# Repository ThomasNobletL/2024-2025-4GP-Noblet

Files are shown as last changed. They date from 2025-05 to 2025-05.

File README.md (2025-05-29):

<h1 align = "center"> Projet Capteur Graphite 4A - GP <h1> 
<h2 align="center"> Par NOBLET Thomas </h2>
<h3 align="center"> INSA de Toulouse, département Génie Physique, année 2024 - 2025 </h3>
  
<p align="center">
  <a href="http://www.gnu.org/licenses/gpl-3.0">
    
  </a>
</p>

## <h2 align = "center"> Mesure de contrainte sous arduino & python d'un capteur graphite <h1>

### 1. Description

*Contexte*

Le projet consiste à reproduire une technologie low-tech de capteur de flexion en graphite, se basant sur l'article "Pencil Drawn Strain Gauges and Chemiresistors on Paper" de Cheng-Wei Lin, Zhibo Zhao, Jaemyung Kim & Jiaxing Huang.

*Principe*

Des traces de crayons sur du papier se comportent comme des résistances dont la valeur varie en fonction de la courbure du papier sur lequel elles sont dessinées. 

*Contenu du projet*

Une [datasheet du capteur](05_DataSheet/Graphite_Sensor_DATA_SHEET.pdf) a pu être réalisée à l'aide d'une carte Arduino Uno, d'un circuit d'amplification (dont le PCB a été réalisé sur KICAD) et d'une interface python.

***Matériel utilisé (non exhaustif)***
- **Capteur de contrainte en graphite** : Mine HB conseillée
- **LTC1050** : Amplificateur du circuit 
- **MCP 41050** : Permet de faire varier le gain du circuit d'amplification
- **Module Bluetooth HC-05** : Récupérer les données en Bluetooth  
- **Ecran OLED SS1306 en I2C** : Affichage des données sur le PCB

### 2. Circuit d'amplification & PCB

Le circuit d'amplification utilise un amplificateur LTC1050 avec un gain de R2/R1. La résistance R1 est un potentiomètre MCP41050 (de 125Ω à 50kΩ) donnant une plage de gain de 2 à 800.

<p align="center">

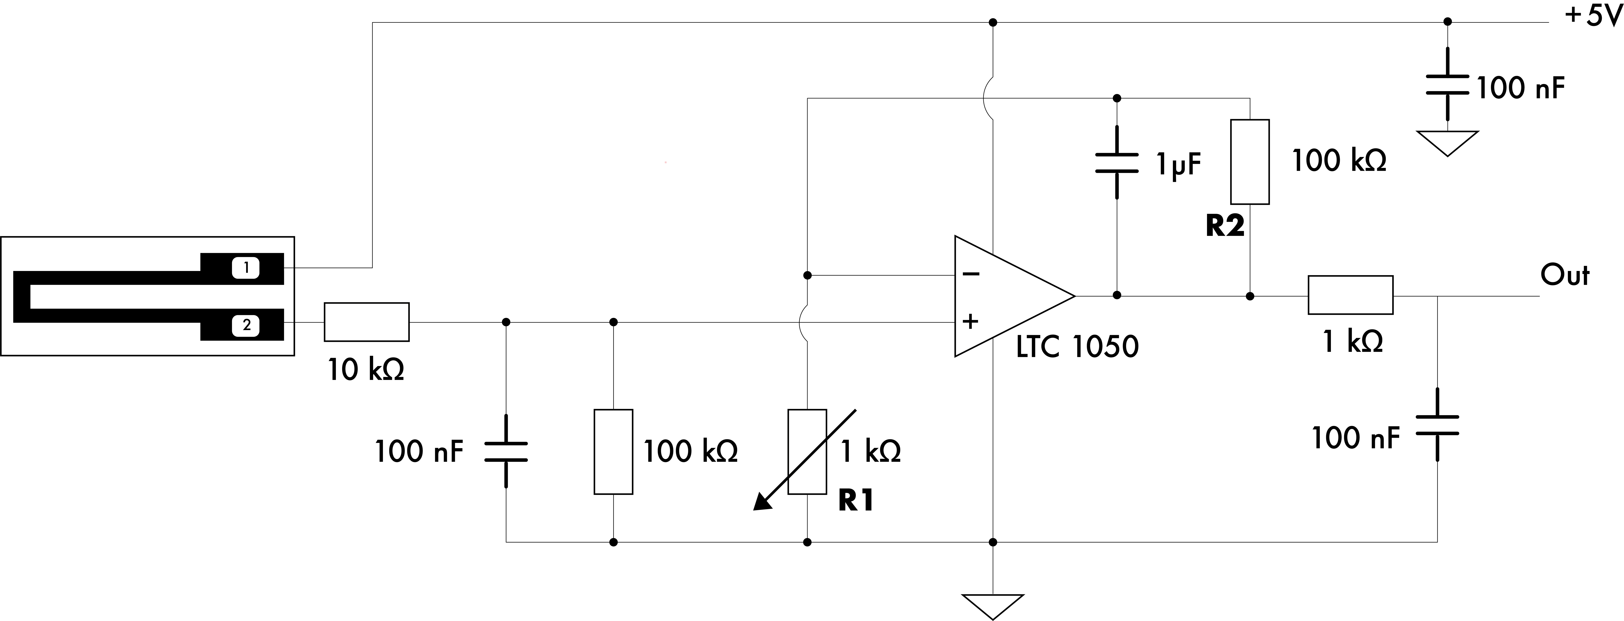
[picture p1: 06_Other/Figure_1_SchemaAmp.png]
Schéma Amplification
  
</p>

<p align="center"><em>Figure 1 : Schéma Amplification </em></p>

<p align="center">

  Circuit réel
</p>
<p align="center"><em>Figure 2 : Circuit réel </em></p>

Le PCB utilisé est celui-ci, avec les pins Rx et Tx de l'arduino connectées au HC05 (PCB Incorrect). Cette configuration est utilisable si on souhaite uploader le code arduino directement en bluetooth, mais il faut impérativement utiliser les pins 2 et 3 pour un upload depuis le port USB. Les pins 0 et 1 sont également utilisées par la liaison série vers un PC, ce qui provoque des erreurs en utilisant la connexion bluetooth sur ce port.

<p align="center">

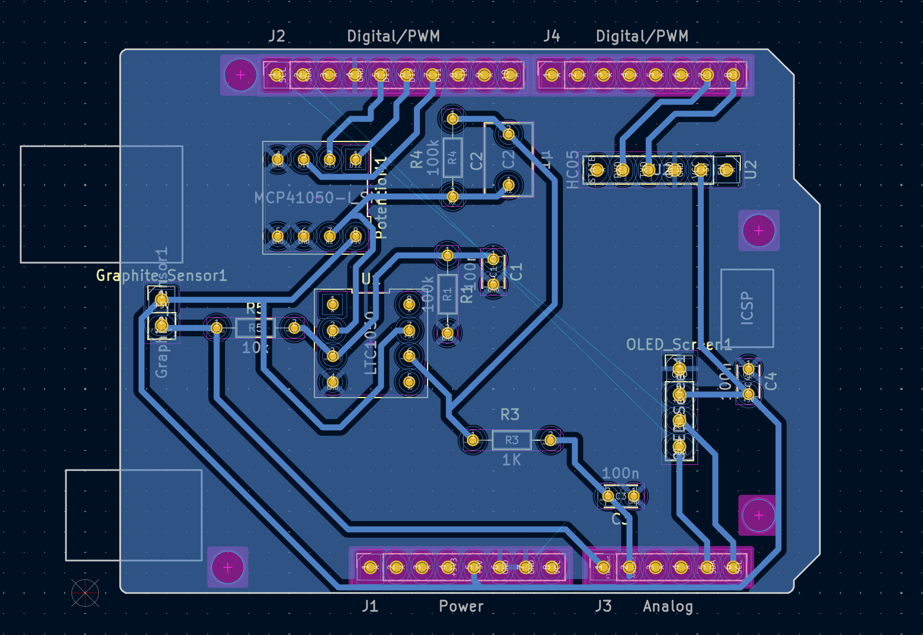
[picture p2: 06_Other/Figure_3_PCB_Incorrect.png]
PCB Incorrect
  
</p>
<p align="center"><em>Figure 3 : PCB Incorrect </em></p>

En l'occurence, aucun des codes python et arduino fournis fonctionnera durablement avec le premier PCB (30s), une erreurs série arrivera relativement rapidement, le PCB a donc été modifié à l'aide de câble pour correspondre à ce nouveau PCB. 

<p align="center">

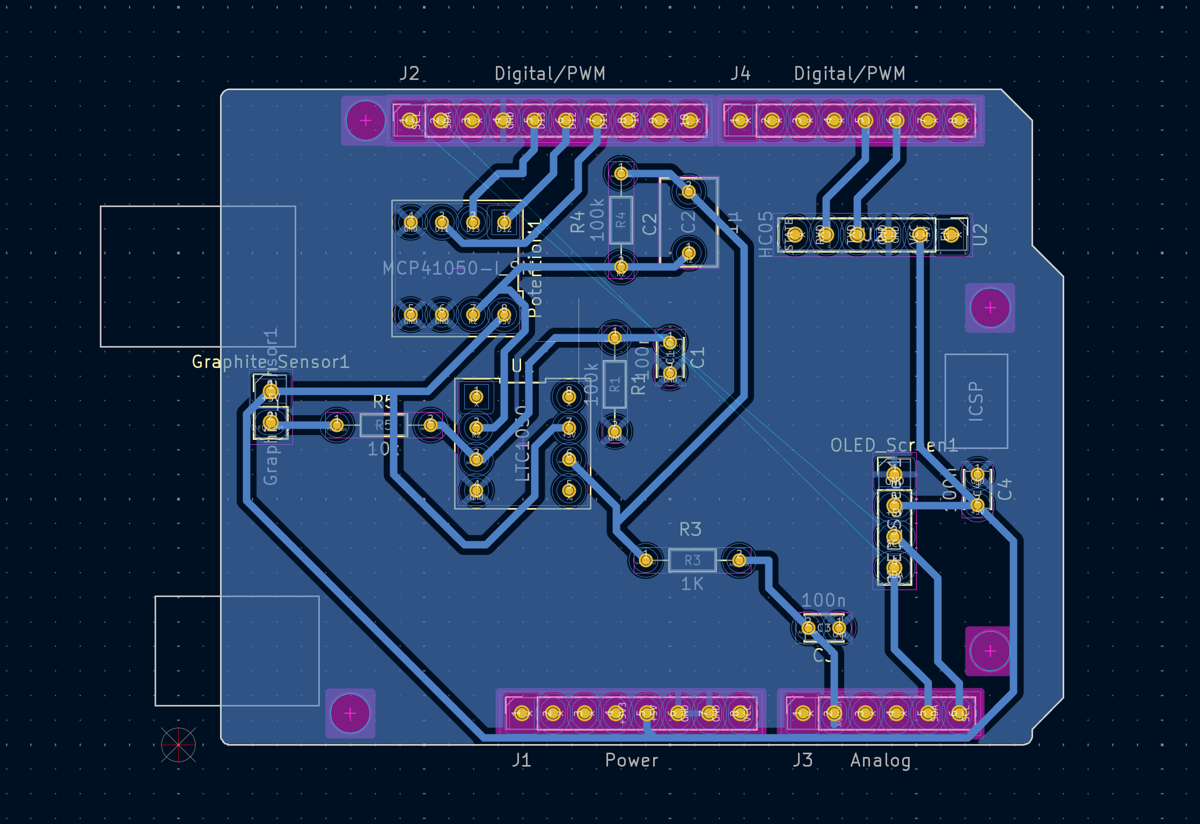
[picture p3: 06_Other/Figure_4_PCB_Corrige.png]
PCB Corrigé
  
</p>
<p align="center"><em>Figure 4 : PCB Corrigé</em></p>

### 3. Interface & code Python 

L'architecture du code est décrite si dessous. La valeur de la résistance ainsi que l'affichage des mesures se fait directement depuis l'interface Qt, qui communique avec un thread gérant l'acquisition et l'envoie de données vers l'arduino qui les réceptionnes. Le code fonctionne à la fois en liaison série et bluetooth, il suffit de choisir depuis "Port choice".

Une valeur du gain observé est affichée dans l'interface, mais ne permet que d'obtenir un ordre de grandeur, la sensibilité des mesures sur l'arduino étant de 4,88 mV et le signal d'entrée trop faible (d'où l'intérêt du circuit d'amplification).

<p align="center">

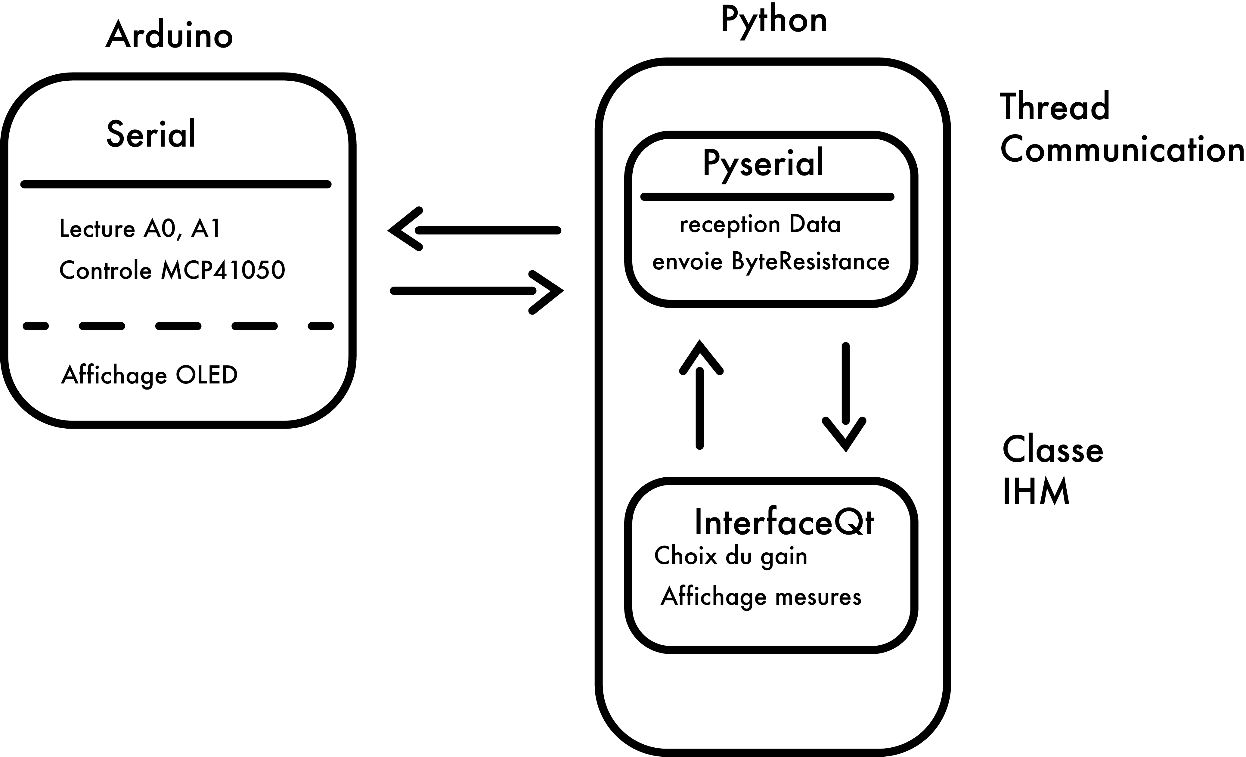
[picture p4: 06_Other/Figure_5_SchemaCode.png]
Architecture du code
  
</p>

<p align="center"><em>Figure 5 : Architecture du code</em></p>

<p align="center">

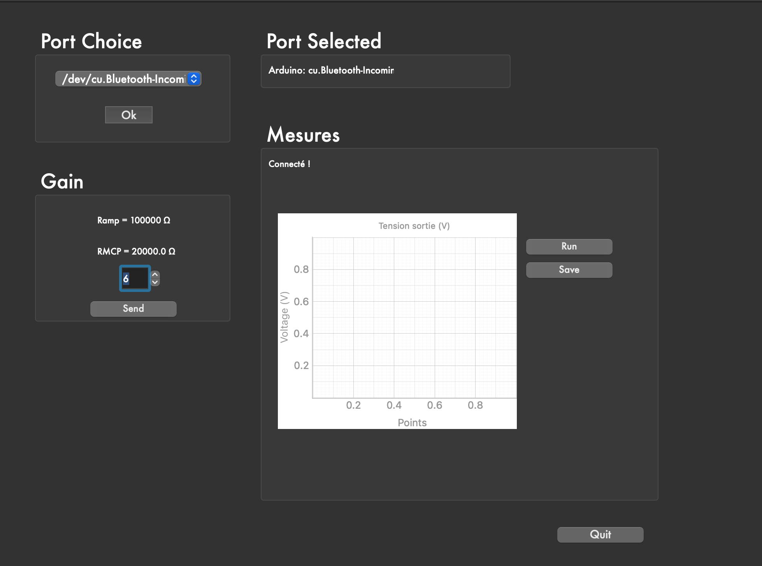
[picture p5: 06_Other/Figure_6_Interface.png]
  
</p>

<p align="center"><em>Figure 5 : Interface Qt</em></p>

Le "run" permet de lancer le stockage des données reçues, mais écrase la précédente série réalisée, il faut donc sauvegarder directement après la fin de l'acquisition si le but est de prendre plusieurs séries d'affilée. 

### 4. Résultats

Les mesures ont été effectuées à l'aide de cylindres de diamètre **D** de **2, 2.5, 3, 3.5, 4, 4.5 et 5 cm** ainsi que de crayons de mines HB, 2B et 4B.
Avec la déformation $\epsilon$ = e/D, e étant l'épaisseur du papier (0,1 mm).

<p align="center">

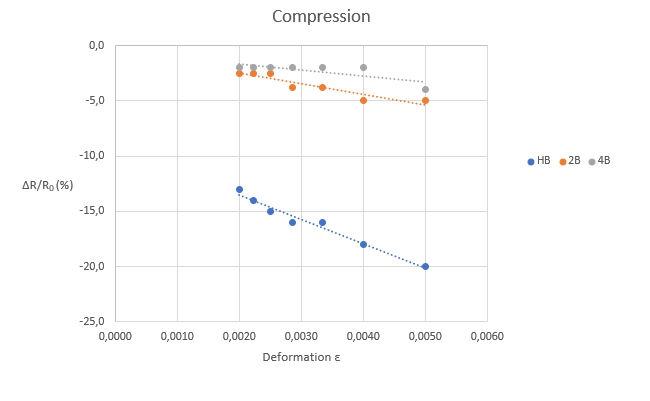
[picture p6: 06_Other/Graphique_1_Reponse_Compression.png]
Réponse en compression
  
</p>

<p align="center"><em>Graphique 1 : Réponse en compression</em></p>

<p align="center">

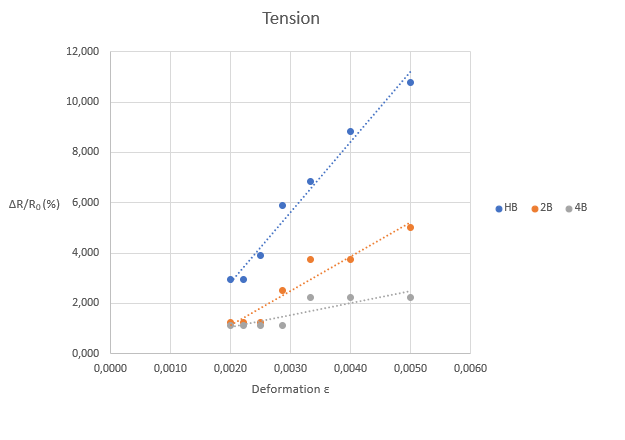
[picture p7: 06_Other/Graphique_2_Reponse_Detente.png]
Réponse en détente
  
</p>
<p align="center"><em>Graphique 2 : Réponse en détente</em></p>

On remarque que la variation de résistance en compression et en détente est plus importante pour une mine moyennement dure et grasse (HB) que pour des mines plus grasses (2B, 4B).

<p align="center">

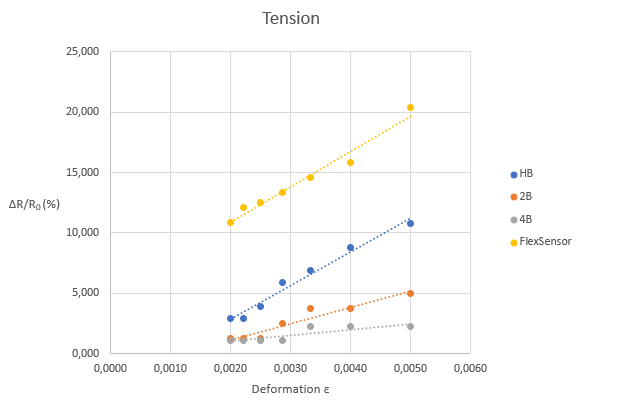
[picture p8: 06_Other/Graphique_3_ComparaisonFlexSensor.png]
Comparaison avec un Flex sensor
  
</p>

<p align="center"><em>Graphique 3 : Comparaison avec un Flex sensor  </em></p>

En comparant avec un flex sensor de Spectra Symbol, on remarque que la réponse en détente est assez cohérente avec celle du capteur en graphite produit (le flex sensor de Spectra Symbol ne permet pas de comparer en compression, [Datasheet](06_Other/FLEX_SENSOR_-_SPECIAL_EDITION_DATA_SHEET.pdf)). De plus, les mesures on étés prises sans utiliser le circuit d'amplification. 

### 5. Limites et perspectives

*Le Bluetooth du HC-05*

  La connexion entre le module HC-05 et un PC est **trop instable** pour utiliser seulement l'interface python fournie **sur Mac OS**, l'appairage échoue souvent ou se coupe régulièrement. Il est préférable d'utiliser une connexion avec un port série. 
  
*Utilisation d'un module Wifi ESP32*

  Remplacer le HC-O5 par un module Wifi ESP32 pourrait permettre de se connecter plus aisément avec les OS Mac sur un même réseau et également en bluetooth.

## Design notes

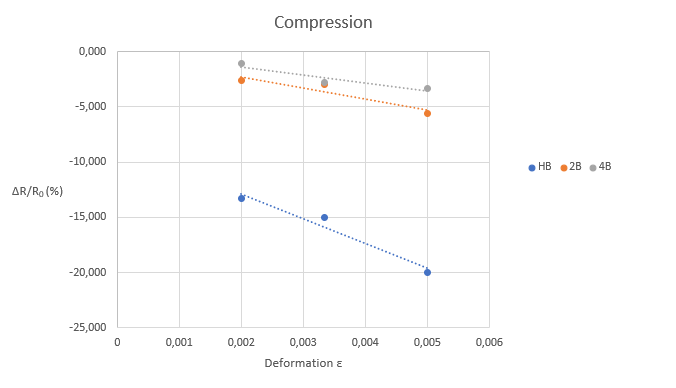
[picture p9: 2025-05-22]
06_Other/01_Preparations/Compression_from_Pc.png

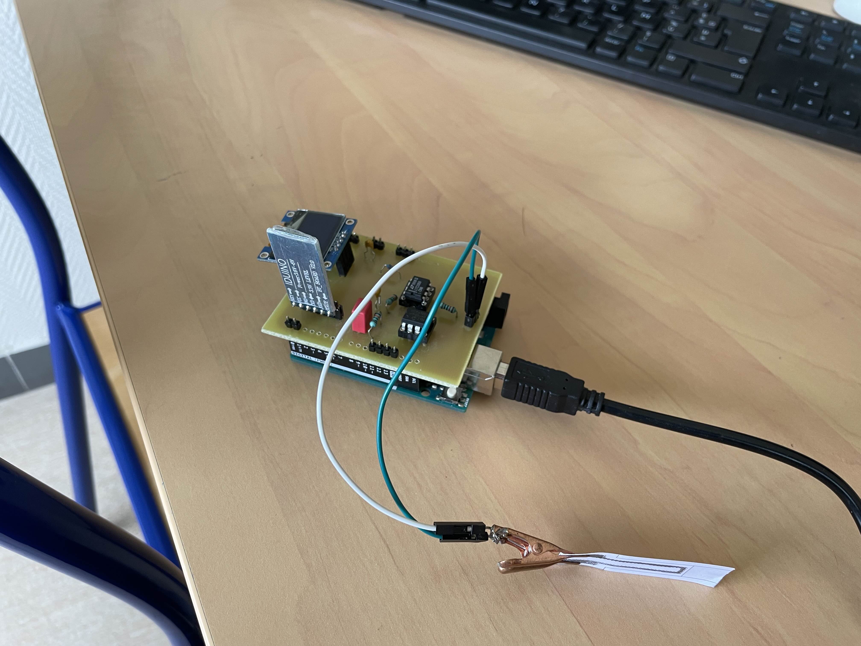
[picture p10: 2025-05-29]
06_Other/01_Preparations/Figure_2_Final.jpg

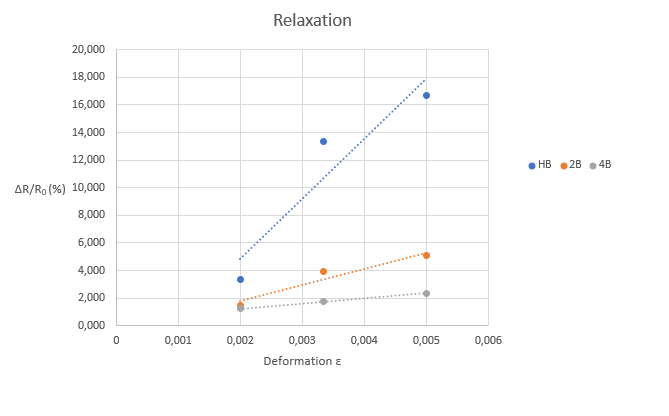
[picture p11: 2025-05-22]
06_Other/01_Preparations/Relaxation_from_Pc.png

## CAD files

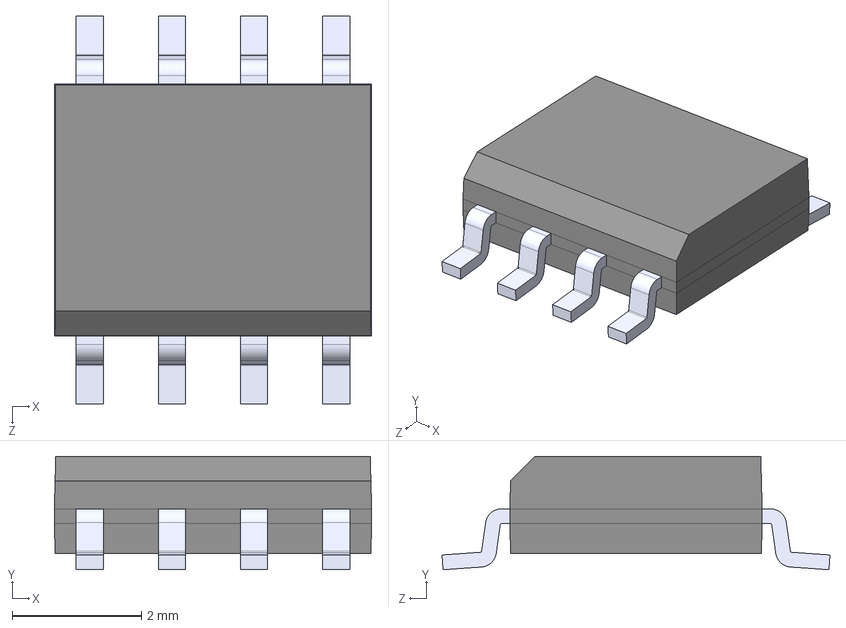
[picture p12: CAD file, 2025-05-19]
02_Kicad/04_Empreinte_from_Web/LTC1050HS8_TRPBF/LTC1050HS8_TRPBF.step
4.90 x 1.75 x 5.99 mm

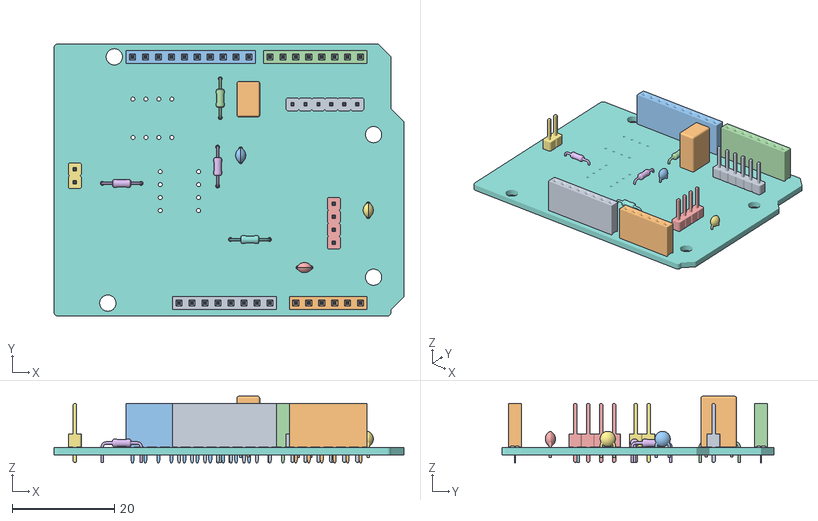
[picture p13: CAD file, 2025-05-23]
06_Other/01_Preparations/PCB-Blender.obj
68.6 x 53.3 x 13.1
PinSocket_1x08_P2.54mm_Vertical
PinSocket_1x06_P2.54mm_Vertical
PinSocket_1x10_P2.54mm_Vertical
PinSocket_1x08_P2.54mm_Vertical001
C_Disc_D3.0mm_W2.0mm_P2.50mm
R_Axial_DIN0204_L3.6mm_D1.6mm_P7.62mm_Horizontal
PinHeader_1x02_P2.54mm_Vertical
R_Axial_DIN0204_L3.6mm_D1.6mm_P7.62mm_Horizontal001
PinHeader_1x06_P2.54mm_Vertical
C_Rect_L7.0mm_W4.5mm_P5.00mm
C_Disc_D3.0mm_W2.0mm_P2.50mm001
R_Axial_DIN0204_L3.6mm_D1.6mm_P7.62mm_Horizontal002
PinHeader_1x04_P2.54mm_Vertical
R_Axial_DIN0204_L3.6mm_D1.6mm_P7.62mm_Horizontal003
C_Disc_D3.0mm_W2.0mm_P2.50mm002
Graphite_PCB

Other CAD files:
06_Other/Graphite.step
02_Kicad/04_Empreinte_from_Web/MCP41050-I_SN/MCP41050-I_SN.step

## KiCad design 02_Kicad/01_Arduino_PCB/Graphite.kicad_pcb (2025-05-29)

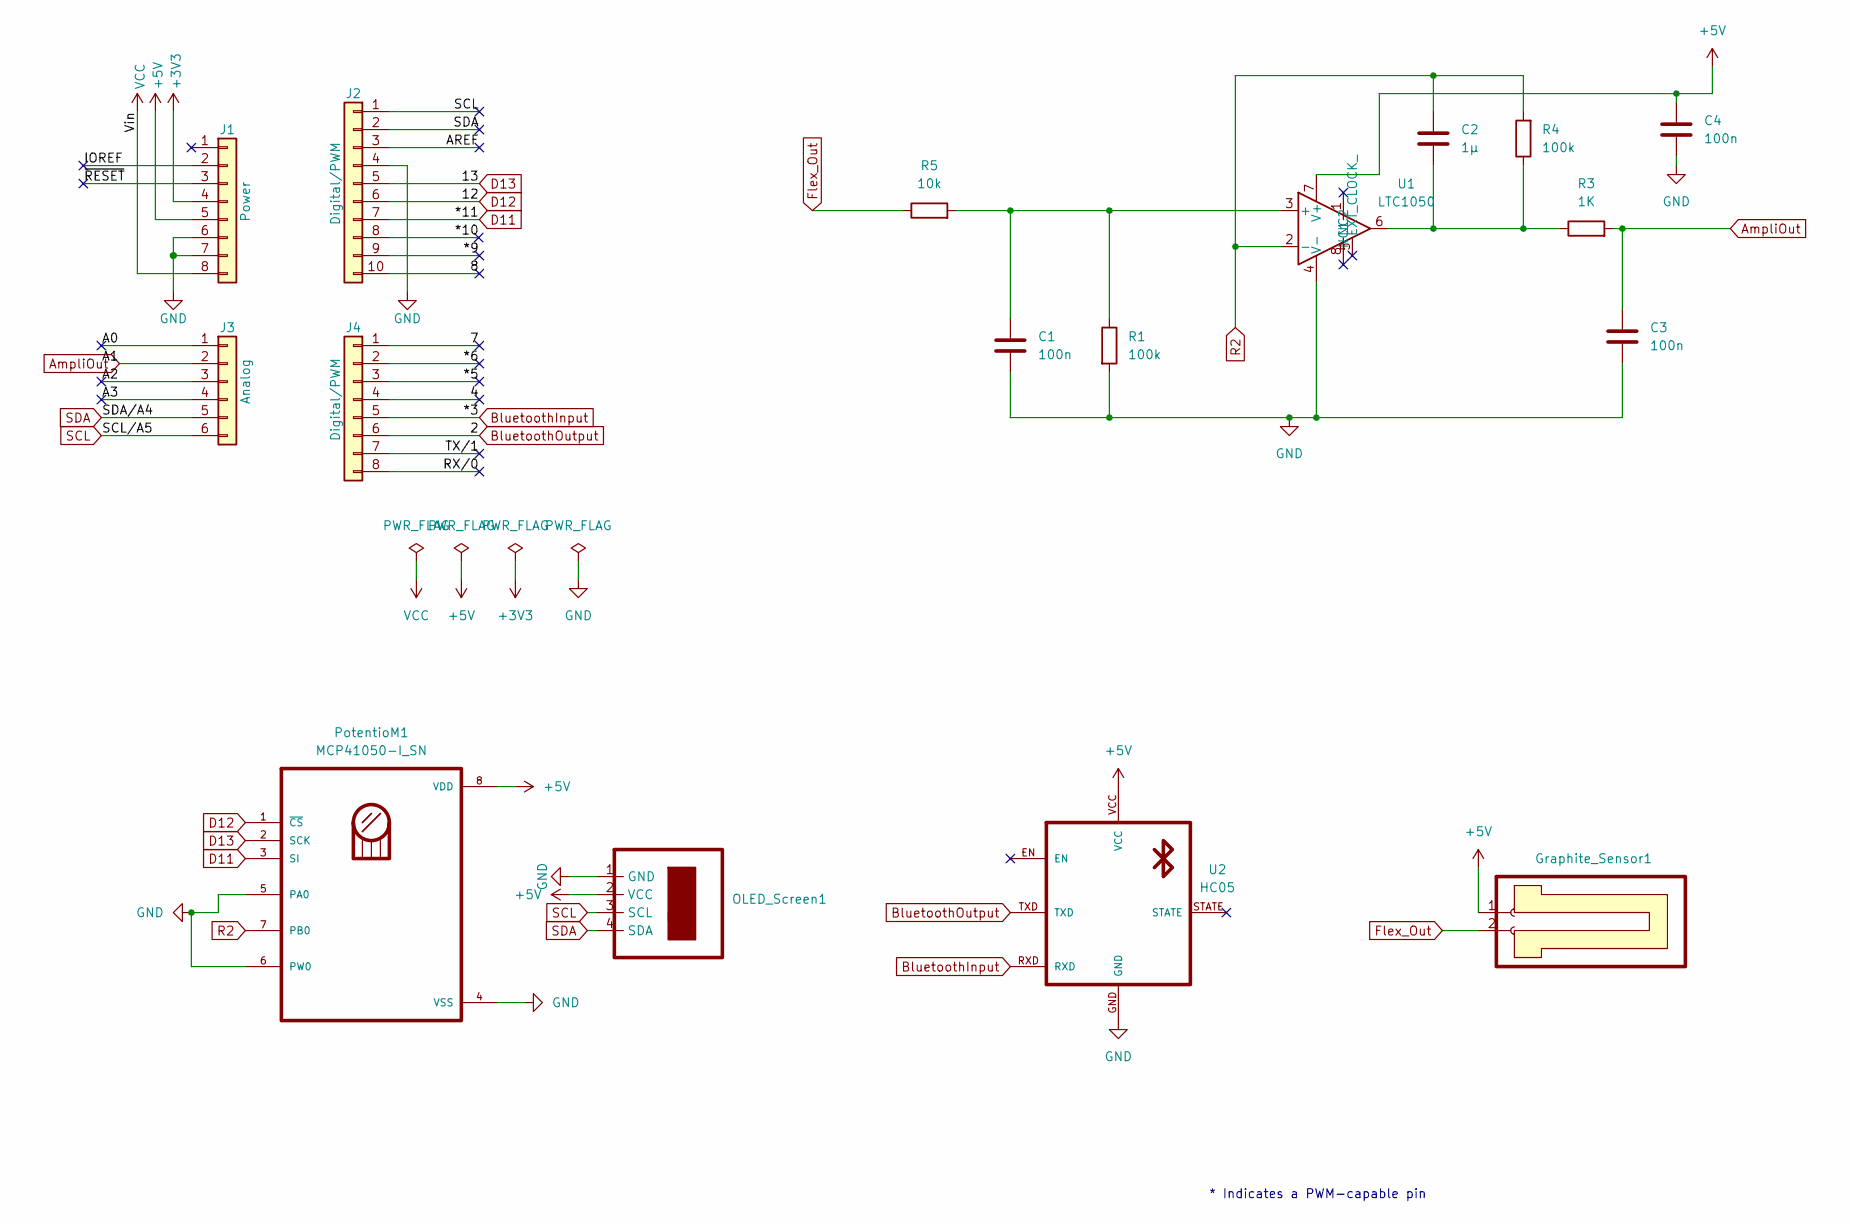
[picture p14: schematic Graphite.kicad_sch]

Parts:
C1, C3, C4: 100n; C_Disc_D3.0mm_W2.0mm_P2.50mm
C2: 1µ; C_Rect_L7.0mm_W4.5mm_P5.00mm
Graphite_Sensor1: Sensor
J1: Power; PinSocket_1x08_P2.54mm_Vertical
J2: Digital/PWM; PinSocket_1x10_P2.54mm_Vertical
J3: Analog; PinSocket_1x06_P2.54mm_Vertical
J4: Digital/PWM; PinSocket_1x08_P2.54mm_Vertical
OLED_Screen1: OLED
PotentioM1: MCP41050-I_SN; MCP41050
R1, R4: 100k; R_Axial_DIN0204_L3.6mm_D1.6mm_P7.62mm_Horizontal
R3: 1K; R_Axial_DIN0204_L3.6mm_D1.6mm_P7.62mm_Horizontal
R5: 10k; R_Axial_DIN0204_L3.6mm_D1.6mm_P7.62mm_Horizontal
U1: LTC1050
U2: HC05; HCO5

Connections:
+3V3: J1.4
+5V: C4.2, Graphite_Sensor1.1 (VCC), J1.5, OLED_Screen1.2 (VCC), PotentioM1.8 (VDD), U1.7 (V+), U2.VCC
/4: J4.4
/7: J4.1
/8: J2.10
/*5: J4.3
/*6: J4.2
/*9: J2.9
/*10: J2.8
/A0: J3.1
/A2: J3.3
/A3: J3.4
/AREF: J2.3
/IOREF: J1.2
/RX/0: J4.8
/TX/1: J4.7
/~RESET: J1.3
AmpliOut: C3.2, J3.2, R3.2
BluetoothInput: J4.5, U2.RXD
BluetoothOutput: J4.6, U2.TXD
D11: J2.7, PotentioM1.3 (SI)
D12: J2.6, PotentioM1.1 (~CS)
D13: J2.5, PotentioM1.2 (SCK)
Flex_Out: Graphite_Sensor1.2 (OutPut), R5.1
GND: C1.2, C3.1, C4.1, J1.6, J1.7, J2.4, OLED_Screen1.1 (GND), PotentioM1.4 (VSS), PotentioM1.5 (PA0), PotentioM1.6 (PW0), R1.2, U1.4 (V-), U2.GND
unnamed: C2.2, R3.1, R4.1, U1.6
unnamed: C1.1, R1.1, R5.2, U1.3 (+)
R2: C2.1, PotentioM1.7 (PB0), R4.2, U1.2 (-)
SCL: J2.1, J3.6, OLED_Screen1.3 (SCL)
SDA: J2.2, J3.5, OLED_Screen1.4 (SDA)
VCC: J1.8

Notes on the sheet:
* Indicates a PWM-capable pin

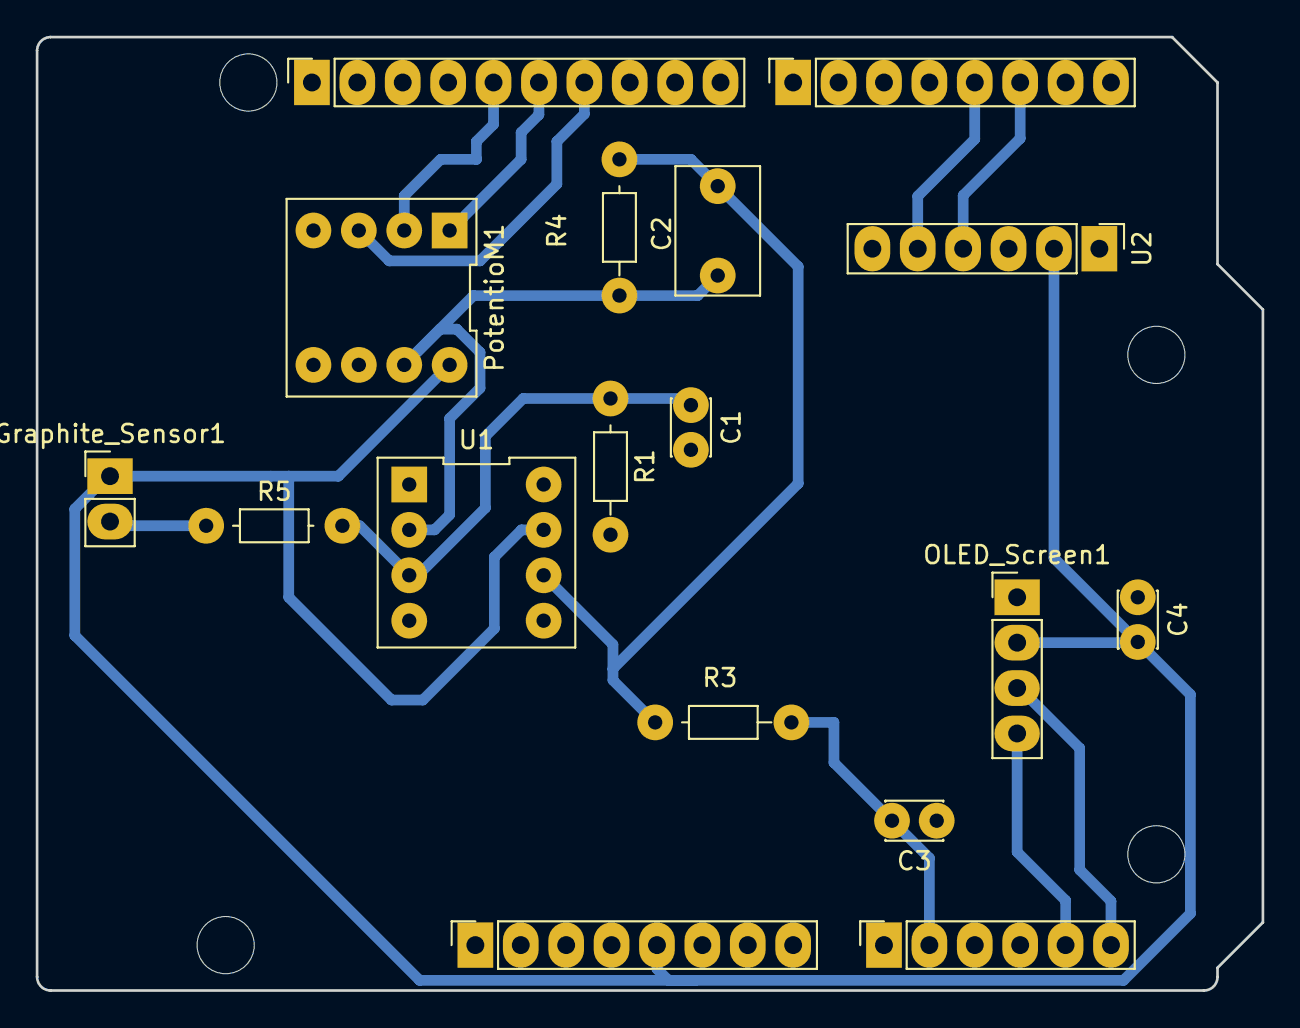
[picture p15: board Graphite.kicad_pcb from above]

Board: 2 copper layers, 68.6 x 53.3 mm, 21 parts (0 on the bottom side), 14 nets.

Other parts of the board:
MH1, MH2, MH3, MH4: MountingHole_3.2mm

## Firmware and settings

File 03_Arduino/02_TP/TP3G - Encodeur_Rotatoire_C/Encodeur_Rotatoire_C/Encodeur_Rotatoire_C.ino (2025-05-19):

/* Read a rotary encoder with interrupts
   Encoder hooked up with common to GROUND,    encoder0PinA to pin 2, encoder0PinB to pin 4
   it doesn't matter which encoder pin you use for A or B  
*/ 

#define encoder0PinA  2  //CLK Output A Do not use other pin for clock as we are using interrupt
#define encoder0PinB  4  //DT Output B
#define Switch 5 // Switch connection if available

volatile int encoder0Pos = 0;

void setup() { 
  pinMode(encoder0PinA, INPUT); 
  digitalWrite(encoder0PinA, HIGH);       // turn on pullup resistor

  pinMode(encoder0PinB, INPUT); 
  digitalWrite(encoder0PinB, HIGH);       // turn on pullup resistor

  attachInterrupt(0, doEncoder, RISING); // encoder pin on interrupt 0 - pin2

  Serial.begin (9600);
  Serial.println("start");                // a personal quirk
} 

void loop(){
  //do some stuff here - the joy of interrupts is that they take care of themselves
  //Serial.print("Position:");
  Serial.println (encoder0Pos, DEC);  //Angle = (360 / Encoder_Resolution) * encoder0Pos
}

void doEncoder() {
  if (digitalRead(encoder0PinA)==HIGH && digitalRead(encoder0PinB)==HIGH) {
    encoder0Pos++;
  } else if (digitalRead(encoder0PinA)==HIGH && digitalRead(encoder0PinB)==LOW) {
    encoder0Pos--;
  }
  // Serial.println (encoder0Pos, DEC);  //Angle = (360 / Encoder_Resolution) * encoder0Pos
}

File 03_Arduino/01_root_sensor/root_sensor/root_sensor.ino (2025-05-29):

#include <SPI.h>
#include <LiquidCrystal_I2C.h>
#include <SoftwareSerial.h>

//Definition du BaudRate
#define baudrate 9600

//Definitions des pins
#define Rx 2 //Vers le TX du HCO5
#define Tx 3 //Vers le RX du HCO5

#define OutRaw A0 // Sortie directe depuis le capteur graphite
#define OutAmp A1 // Sortie amplifiée par le LTC1050 du capteur graphite

#define MOSI 11 // entrée de commandes du MCP41050
#define CS 12 // Chip select du MCP41050
#define SCK 13 // serial Clock du MCP41050

//Definition des valeurs fixes

#define Rab 50000 // Resistance MAX du MCP41050
#define Rw 125 //Resistance Interne du MCP41050

//Adresse du LCD
LiquidCrystal_I2C lcd(0x27, 16, 2);

//Valeur de base de la résistance du MCP41050
byte resistanceValue = 0; //Resistance de base : 125 Ohms, Gain de base : 3 

// Pour stocker les commandes Bluetooth
String inputBuffer = ""; 

//Connection du HC05 avec les Tx & Rx de l'arduino
SoftwareSerial BTserial(Rx, Tx);


void setup() {
  Serial.begin(baudrate);       // Moniteur série USB

  BTserial.begin(baudrate);     // Communication Bluetooth HC-05

  pinMode(CS, OUTPUT);          //Initialisation du MCP41050
  digitalWrite(CS, HIGH);
  SPI.begin();
  setResistance(resistanceValue);

  lcd.init();            // Initialisation de l'écran
  lcd.backlight();       
  lcd.setCursor(0, 0);   
  lcd.print("LCD Start");
  delay(1000);
}

void loop() {
  // Lire les tensions A0 et A1 
  int valA0 = analogRead(OutRaw);
  int valA1 = analogRead(OutAmp);

  
  // Lecture des données reçues Bluetooth
  while (BTserial.available()) {
    char c = BTserial.read();

    if (c == '\n' || c == '\r') {
      processCommand(inputBuffer);
      inputBuffer = "";
    } else {
      inputBuffer += c;
    }
  }
  // Lecture des données reçues en série 
while (Serial.available()) {
    char c = Serial.read();
    if (c == '\n' || c == '\r') {
      processCommand(inputBuffer);
      inputBuffer = "";
    } else {
      inputBuffer += c;
    }
  }
  // Envoi des données en Bluetooth et en série
  String message = String(valA0) + "," + String(valA1) +"\n";
  BTserial.print(message);
  Serial.print(message);

  float tensA1 = valA1*5.0/1023;
  char TabA1[5]; 
  dtostrf(tensA1, 4, 2, TabA1);

  float gain = (valA0 != 0) ? (float)valA1 / valA0 : 0.0;
  char TabGain[5]; 
  dtostrf(gain, 4, 2, TabGain);
  ScreenDisp (TabA1, TabGain);

  delay(500);
}

//Affichage des valeurs de tensions sur l'écran LCD
void ScreenDisp(char* tension, char* gain) {
  lcd.setCursor(0, 0);
  lcd.print("Out: ");
  lcd.print(tension);
  lcd.print("V");
  lcd.setCursor(0, 1);
  lcd.print("Gain: ");
  lcd.print(gain);

  }

  //Changement de résistances sur le MCP41050, de 50k à 125
void setResistance(byte value) {
  digitalWrite(CS, LOW);  
  SPI.transfer(0x11);  
  SPI.transfer(value);
  digitalWrite(CS, HIGH);
}

// Gestions des commandes reçues en bluetooth et en série

void processCommand(String cmd) {
  cmd.trim();
  cmd.toUpperCase();

  if (cmd.startsWith("SET")) {
    int val = cmd.substring(3).toInt();
    if (val >= 0 && val <= 255) {    //Vérification que la valeur envoyée est dans la plage
      resistanceValue = val;
      Serial.println(val);
      setResistance(resistanceValue);
      Serial.print("Resistance set to ");
      Serial.println(resistanceValue);
    } else {
      Serial.print("Value out of range (0-255)");
    }

  } else {
    Serial.print("Unknown command"); //Affichage de l'erreur sur le moniteur série
    Serial.println(cmd);
  }
}

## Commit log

2025-05-19 Ajout dossiers precedents
    [Graphite.kicad_pcb, Graphite.kicad_sch, LTC1050HS8_TRPBF.step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]
2025-05-19 Rectification Kicad
    [Graphite.kicad_pcb, Graphite.kicad_sch]
2025-05-19 Ajouter MCP41050 resistances
2025-05-20 Code Arduino LCD
2025-05-22 ajout images
    [Graphite.kicad_pcb, Graphite.kicad_sch, Graphite.step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]
2025-05-22 correction !=0 sensor
2025-05-23 Gain code correction
    [PCB-Blender.obj]
2025-05-29 Ajout Nouvelles mesures
    [Graphite.kicad_pcb, Graphite.kicad_sch, PCB-Blender.obj]

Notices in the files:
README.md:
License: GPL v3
